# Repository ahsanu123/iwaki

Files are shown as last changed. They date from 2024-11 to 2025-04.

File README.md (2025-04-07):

<p>
  <a href="">
    
  </a>
  <a href="">
    
  </a>
  <a href="">
    
  </a>
  <a href="https://github.com/ahsanu123/iwaki/blob/main/LICENSE">
    
  </a>
</p>

<p align="center">
   <br/>
   Automated Fish Cultivation
</p>

# 🐟 IWAKI - Automated Fish Cultivation

Initial System Design 

```mermaid
---
title: Block Diagram of System
---
classDiagram

note for DCMotor "this will use for spreading food"
note for Board "Use ESP32 to send data into server"
note for Spreader "Mechanic Spreader"

PowerSupply <|-- Board 
Board <|-- DCMotor
Board <|-- TempSensor
Board <|-- ESP32
Board <|-- SalinityAndPH
Board <|-- SSR
Board <|-- IOExpantion

IOExpantion <|-- SolenoidValve

SSR <|-- Pump

Spreader <|-- Board
Hopper <|-- Spreader

Server <|-- Board
Server <|-- Mobile

namespace Electronic {
class IOExpantion
class SalinityAndPH
class Board
class DCMotor
class ESP32
class TempSensor
class SSR
}

namespace Feeder{
class Spreader
class Hopper
}

namespace App{
class Mobile
}

namespace Backend{
class Server
}

```

## 🌳 Logs
- create initial system design, 23 november 2024 at ⏰ 14:26
- decided to use [embassy rust](https://github.com/embassy-rs/embassy) to do firmware, 16 januari 2025 at ⏰ 18:47 

## 🎈 Reference 

- [A Guide to Recirculation Aquaculture](https://openknowledge.fao.org/server/api/core/bitstreams/a0297773-095a-4ae7-9a89-5a3bfb48abc7/content)
- [efishery guide on lele RAS](https://efishery.com/id/resources/budidaya-ikan-lele-sistem-ras/)
- [a freecad manual](https://www.freecad.org/manual/a-freecad-manual.pdf)

<sub>long project with hope will finish. made with ♥️ by ah...</sub>

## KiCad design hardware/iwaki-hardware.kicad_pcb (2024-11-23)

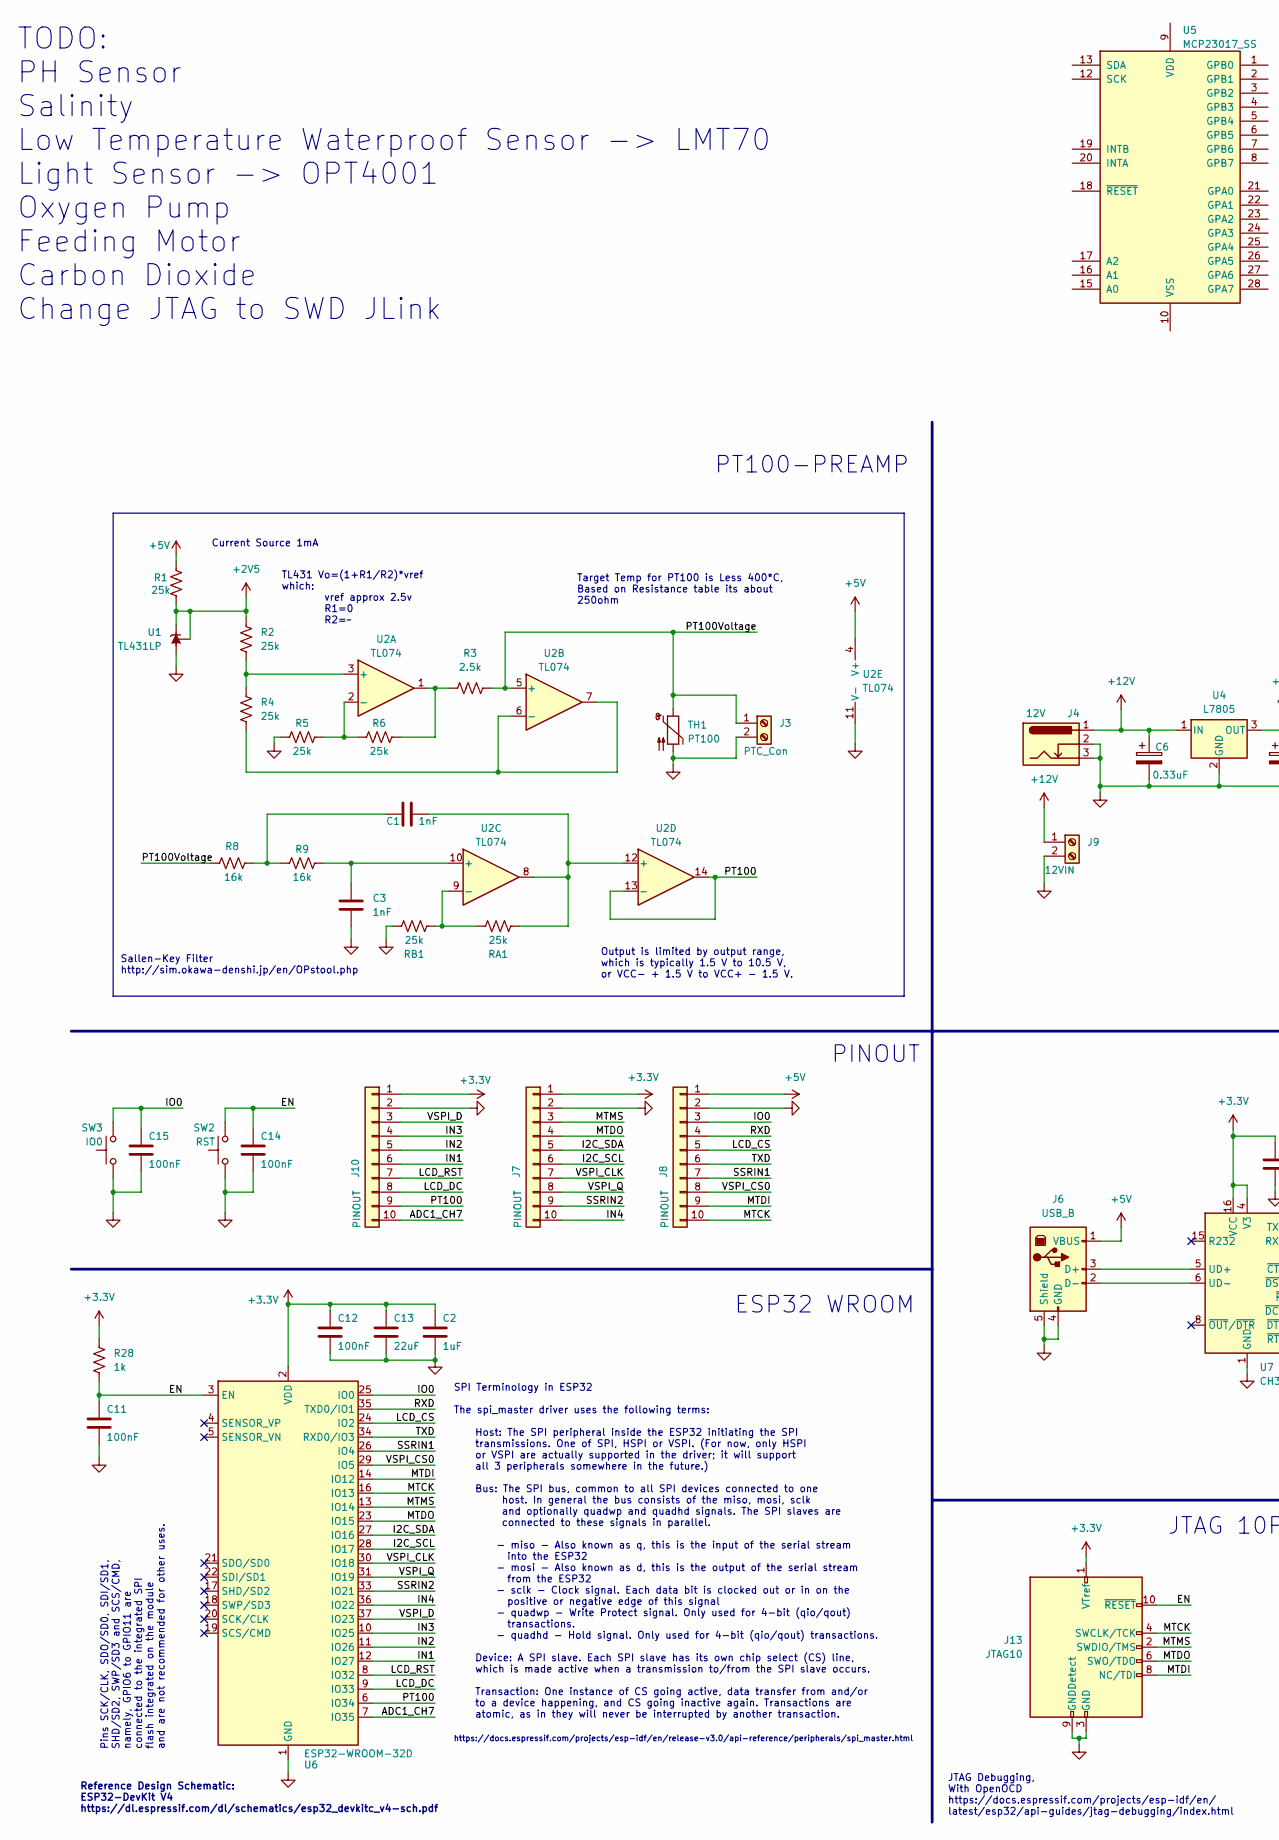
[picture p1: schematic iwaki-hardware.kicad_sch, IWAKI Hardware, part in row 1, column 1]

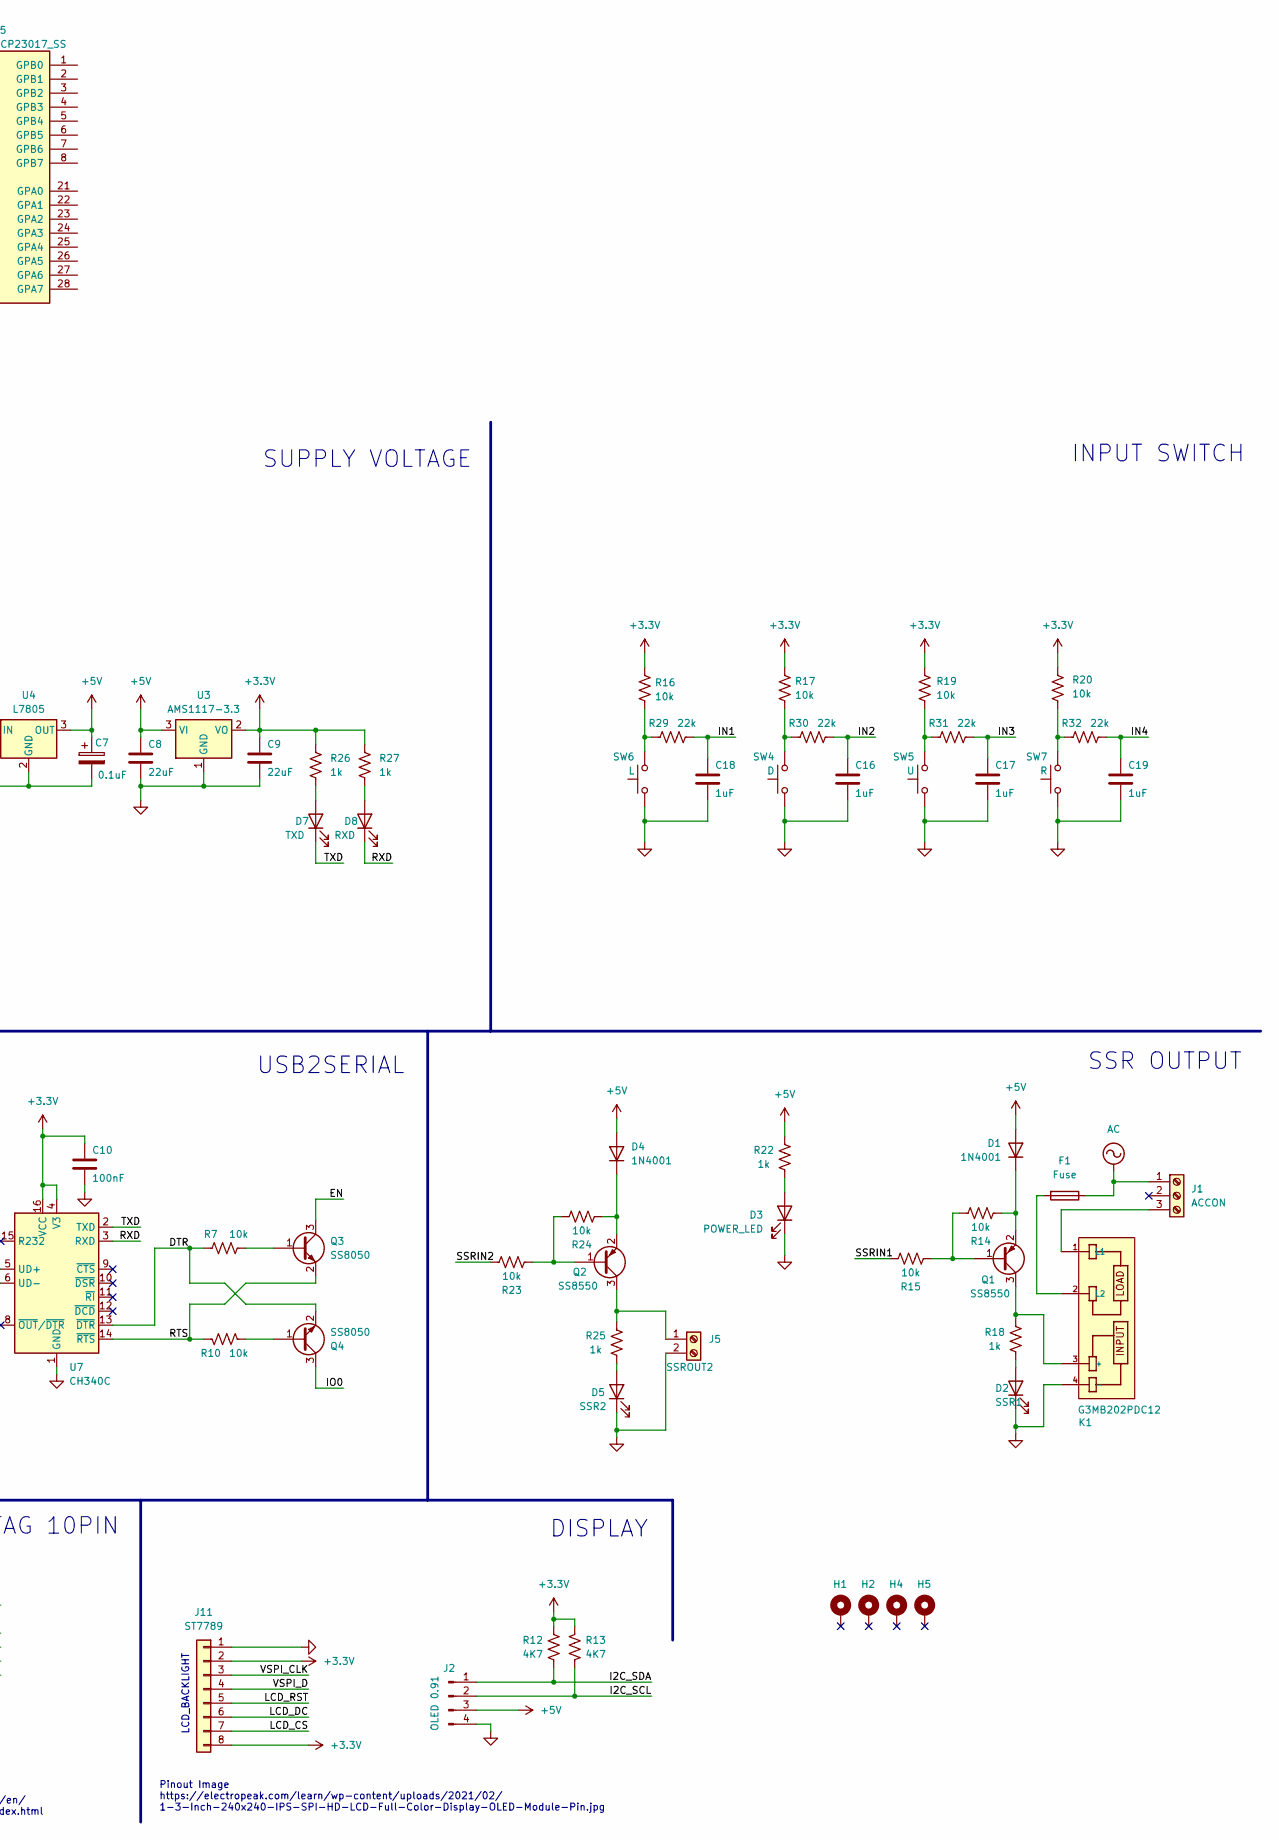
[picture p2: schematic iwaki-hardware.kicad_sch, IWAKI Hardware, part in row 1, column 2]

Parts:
C1, C3: 1nF; C_0805_2012Metric_Pad1.18x1.45mm_HandSolder
C2, C16, C17, C18, C19: 1uF; C_0805_2012Metric_Pad1.18x1.45mm_HandSolder
C6: 0.33uF; C_0805_2012Metric_Pad1.18x1.45mm_HandSolder
C7: 0.1uF; C_0805_2012Metric_Pad1.18x1.45mm_HandSolder
C8, C9, C13: 22uF; C_0805_2012Metric_Pad1.18x1.45mm_HandSolder
C10, C11, C12, C14, C15: 100nF; C_0805_2012Metric_Pad1.18x1.45mm_HandSolder
D1, D4: 1N4001; D_SOD-123
D2: SSR1; LED_1206_3216Metric_Pad1.42x1.75mm_HandSolder
D3: POWER_LED; LED_1206_3216Metric_Pad1.42x1.75mm_HandSolder
D5: SSR2; LED_1206_3216Metric_Pad1.42x1.75mm_HandSolder
D7: TXD; LED_1206_3216Metric_Pad1.42x1.75mm_HandSolder
D8: RXD; LED_1206_3216Metric_Pad1.42x1.75mm_HandSolder
F1: Fuse; Fuseholder_Littelfuse_100_series_5x30mm
H1, H2, H4, H5: MountingHole_Pad; MountingHole_3.2mm_M3_DIN965_Pad
J1: ACCON; TerminalBlock_Phoenix_PT-1,5-3-5.0-H_1x03_P5.00mm_Horizontal
J2: OLED 0.91; PinHeader_1x04_P2.54mm_Vertical
J3: PTC_Con; TerminalBlock_Phoenix_PT-1,5-2-5.0-H_1x02_P5.00mm_Horizontal
J4: 12V; BarrelJack_Horizontal
J5: SSROUT2; TerminalBlock_Phoenix_PT-1,5-2-5.0-H_1x02_P5.00mm_Horizontal
J6: USB_B; USB_B_OST_USB-B1HSxx_Horizontal
J7, J8, J10: PINOUT; PinHeader_1x10_P2.54mm_Vertical
J9: 12VIN; TerminalBlock_Phoenix_PT-1,5-2-5.0-H_1x02_P5.00mm_Horizontal
J11: ST7789; PinSocket_1x08_P2.54mm_Vertical
J13: JTAG10; PinHeader_2x05_P2.54mm_Vertical
K1: G3MB202PDC12; RELAY_G3MB202PDC12; PARTREV N/A
Q1, Q2: SS8550; SOT-23_Handsoldering
Q3, Q4: SS8050; SOT-23_Handsoldering
R1, R2, R4, R5, R6: 25k; R_0805_2012Metric_Pad1.20x1.40mm_HandSolder
R3: 2.5k; R_0805_2012Metric_Pad1.20x1.40mm_HandSolder
R7, R10, R14, R15, R16, R17, R19, R20, R23, R24: 10k; R_0805_2012Metric_Pad1.20x1.40mm_HandSolder
R8, R9: 16k; R_0805_2012Metric_Pad1.20x1.40mm_HandSolder
R12, R13: 4K7; R_0805_2012Metric_Pad1.20x1.40mm_HandSolder
R18, R22, R25, R26, R27, R28: 1k; R_0805_2012Metric_Pad1.20x1.40mm_HandSolder
R29, R30, R31, R32: 22k; R_0805_2012Metric_Pad1.20x1.40mm_HandSolder
RA1: 25k; R_0805_2012Metric_Pad1.20x1.40mm_HandSolder
RB1: 25k; R_0805_2012Metric_Pad1.20x1.40mm_HandSolder
SW2: RST; SW_Push_1P1T_NO_6x6mm_H9.5mm
SW3: IO0; SW_Push_1P1T_NO_6x6mm_H9.5mm
SW4: D; SW_Push_1P1T_NO_6x6mm_H9.5mm
SW5: U; SW_Push_1P1T_NO_6x6mm_H9.5mm
SW6: L; SW_Push_1P1T_NO_6x6mm_H9.5mm
SW7: R; SW_Push_1P1T_NO_6x6mm_H9.5mm
TH1: PT100; TO-92-2_Horizontal2
U1: TL431LP; TO-92_Inline_Wide
U2: TL074; SOIC-14_3.9x8.7mm_P1.27mm
U3: AMS1117-3.3; SOT-223-3_TabPin2
U4: L7805; TO-220F-3_Horizontal_TabDown
U5: MCP23017_SS; SSOP-28_5.3x10.2mm_P0.65mm
U6: ESP32-WROOM-32D
U7: CH340C; SOIC-16_3.9x9.9mm_P1.27mm

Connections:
+2V5: R1.1, R2.1, U1.1 (REF), U1.3 (K)
+3.3V: C2.1, C9.1, C10.1, C12.1, C13.1, J7.1, J10.1, J11.2, J11.8, J13.1 (VTref), R12.2, R13.2, R16.1, R17.1, R19.1, R20.1, R26.1, R27.1, R28.1, U3.2 (VO), U6.2 (VDD), U7.4 (V3), U7.16 (VCC)
+5V: C7.1, C8.1, D1.2 (A), D4.2 (A), J2.3, J6.1 (VBUS), J8.1, R1.2, R22.2, U2.4 (V+), U3.3 (VI), U4.3 (OUT)
+12V: C6.1, J4.1, J9.1, U4.1 (IN)
/ADC1_CH7: J10.10, U6.7 (IO35)
/DTR: Q4.2 (E), R7.2, U7.13 (~DTR)
/EN: C11.1, C14.1, J13.10 (~RESET), Q3.3 (C), R28.2, SW2.2, U6.3 (EN)
/I2C_SCL: J2.2, J7.6, R13.1, U6.28 (IO17)
/I2C_SDA: J2.1, J7.5, R12.1, U6.27 (IO16)
/IN1: C18.1, J10.6, R29.1, U6.12 (IO27)
/IN2: C16.1, J10.5, R30.1, U6.11 (IO26)
/IN3: C17.1, J10.4, R31.1, U6.10 (IO25)
/IN4: C19.1, J7.10, R32.1, U6.36 (IO22)
/IO0: C15.1, J8.3, Q4.3 (C), SW3.2, U6.25 (IO0)
/LCD_CS: J8.5, J11.7, U6.24 (IO2)
/LCD_DC: J10.8, J11.6, U6.9 (IO33)
/LCD_RST: J10.7, J11.5, U6.8 (IO32)
/MTCK: J8.10, J13.4 (SWCLK/TCK), U6.16 (IO13)
/MTDI: J8.9, J13.8 (NC/TDI), U6.14 (IO12)
/MTDO: J7.4, J13.6 (SWO/TDO), U6.23 (IO15)
/MTMS: J7.3, J13.2 (SWDIO/TMS), U6.13 (IO14)
/PT100: J10.9, U2.13 (-), U2.14, U6.6 (IO34)
/PT100Voltage: J3.1, R3.1, R8.2, TH1.1, U2.5 (+)
/RTS: Q3.2 (E), R10.2, U7.14 (~RTS)
/RXD: D8.1 (K), J8.4, U6.35 (TXD0/IO1), U7.3 (RXD)
/SSRIN1: J8.7, R15.1, U6.26 (IO4)
/SSRIN2: J7.9, R23.1, U6.33 (IO21)
/TXD: D7.1 (K), J8.6, U6.34 (RXD0/IO3), U7.2 (TXD)
/VSPI_CLK: J7.7, J11.3, U6.30 (IO18)
/VSPI_CS0: J8.8, U6.29 (IO5)
/VSPI_D: J10.3, J11.4, U6.37 (IO23)
/VSPI_Q: J7.8, U6.31 (IO19)
AC: F1.1, J1.1
GND: C2.2, C3.2, C6.2, C7.2, C8.2, C9.2, C10.2, C11.2, C12.2, C13.2, C14.2, C15.2, C16.2, C17.2, C18.2, C19.2, D2.1 (K), D3.1 (K), D5.1 (K), J2.4, J3.2, J4.2, J4.3, J5.2, J6.4 (GND), J6.5 (Shield), J7.2, J8.2, J9.2, J10.2, J11.1, J13.3 (GND), J13.5 (GND), J13.9 (GNDDetect), K1.4 (-), R5.1, RB1.1, SW2.1, SW3.1, SW4.1, SW5.1, SW6.1, SW7.1, TH1.2, U1.2 (A), U2.11 (V-), U3.1 (GND), U4.2 (GND), U6.1 (GND), U6.15 (GND), U6.38 (GND), U6.39 (GND), U7.1 (GND)
unnamed: C1.2, R8.1, R9.2
unnamed: D1.1 (K), Q1.2 (E), R14.2
unnamed: D2.2 (A), R18.1
unnamed: D3.2 (A), R22.1
unnamed: D4.1 (K), Q2.2 (E), R24.2
unnamed: D5.2 (A), R25.1
unnamed: D7.2 (A), R26.2
unnamed: D8.2 (A), R27.2
unnamed: J1.3, K1.1 (L1)
unnamed: J5.1, Q2.3 (C), R25.2
unnamed: J6.3 (D+), U7.5 (UD+)
unnamed: J6.2 (D-), U7.6 (UD-)
unnamed: K1.3 (+), Q1.3 (C), R18.2
unnamed: F1.2, K1.2 (L2)
unnamed: Q1.1 (B), R14.1, R15.2
unnamed: Q2.1 (B), R23.2, R24.1
unnamed: Q3.1 (B), R7.1
unnamed: Q4.1 (B), R10.1
unnamed: R3.2, R6.1, U2.1
unnamed: R16.2, R29.2, SW6.2
unnamed: R17.2, R30.2, SW4.2
unnamed: R19.2, R31.2, SW5.2
unnamed: R20.2, R32.2, SW7.2
unnamed: R2.2, R4.1, U2.3 (+)
unnamed: R5.2, R6.2, U2.2 (-)
unnamed: R4.2, U2.6 (-), U2.7
unnamed: C3.1, R9.1, U2.10 (+)
unnamed: RA1.1, RB1.2, U2.9 (-)
unnamed: C1.1, RA1.2, U2.8, U2.12 (+)

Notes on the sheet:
Sallen-Key Filter http://sim.okawa-denshi.jp/en/OPstool.php
Reference Design Schematic: ESP32-DevKit V4 https://dl.espressif.com/dl/schematics/esp32_devkitc_v4-sch.pdf
SUPPLY VOLTAGE
TODO: PH Sensor Salinity Low Temperature Waterproof Sensor -> LMT70 Light Sensor -> OPT4001 Oxygen Pump Feeding Motor Carbon Dioxide Change JTAG to SWD JLink
JTAG 10PIN
Output is limited by output range, which is typically 1.5 V to 10.5 V, or VCC- + 1.5 V to VCC+ - 1.5 V.
Pinout Image https://electropeak.com/learn/wp-content/uploads/2021/02/ 1-3-Inch-240x240-IPS-SPI-HD-LCD-Full-Color-Display-OLED-Module-Pin.jpg
ESP32 WROOM
PT100-PREAMP
DISPLAY
Pins SCK/CLK, SDO/SD0, SDI/SD1, SHD/SD2, SWP/SD3 and SCS/CMD, namely, GPIO6 to GPIO11 are connected to the integrated SPI flash integrated on the module and are not recommended for other uses.
TL431 Vo=(1+R1/R2)*vref which: vref approx 2.5v R1=0 R2=~
Target Temp for PT100 is Less 400*C, Based on Resistance table its about 250ohm
PINOUT
Current Source 1mA
JTAG Debugging, With OpenOCD https://docs.espressif.com/projects/esp-idf/en/ latest/esp32/api-guides/jtag-debugging/index.html
SPI Terminology in ESP32 The spi_master driver uses the following terms: Host: The SPI peripheral inside the ESP32 initiating the SPI transmissions. One of SPI, HSPI or VSPI. (For now, only HSPI or VSPI are actually supported in the driver; it will support all 3 peripherals somewhere in the future.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
LCD_BACKLIGHT
USB2SERIAL
INPUT SWITCH
SSR OUTPUT

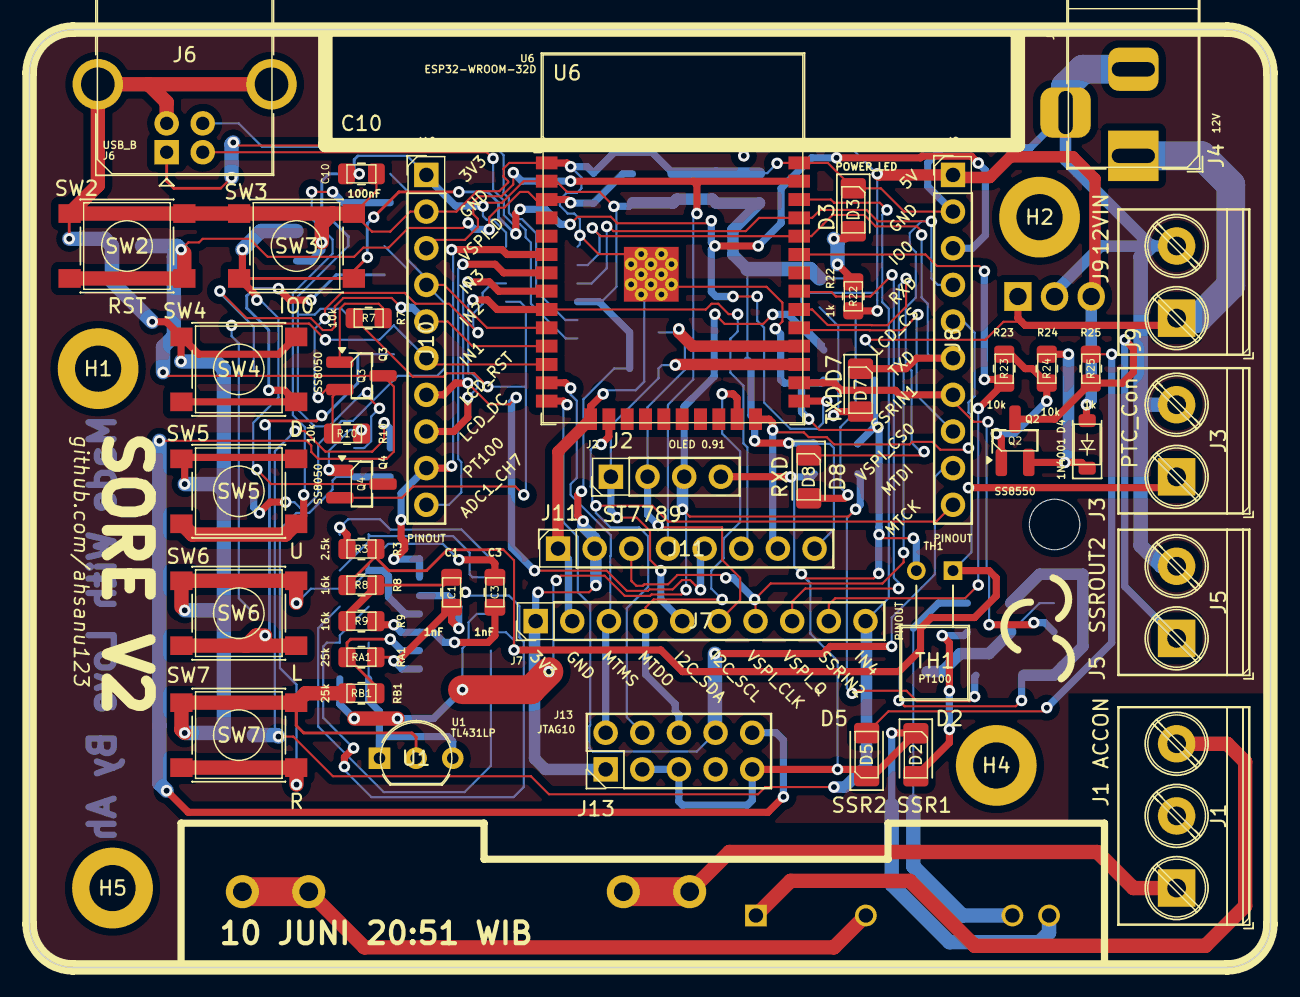
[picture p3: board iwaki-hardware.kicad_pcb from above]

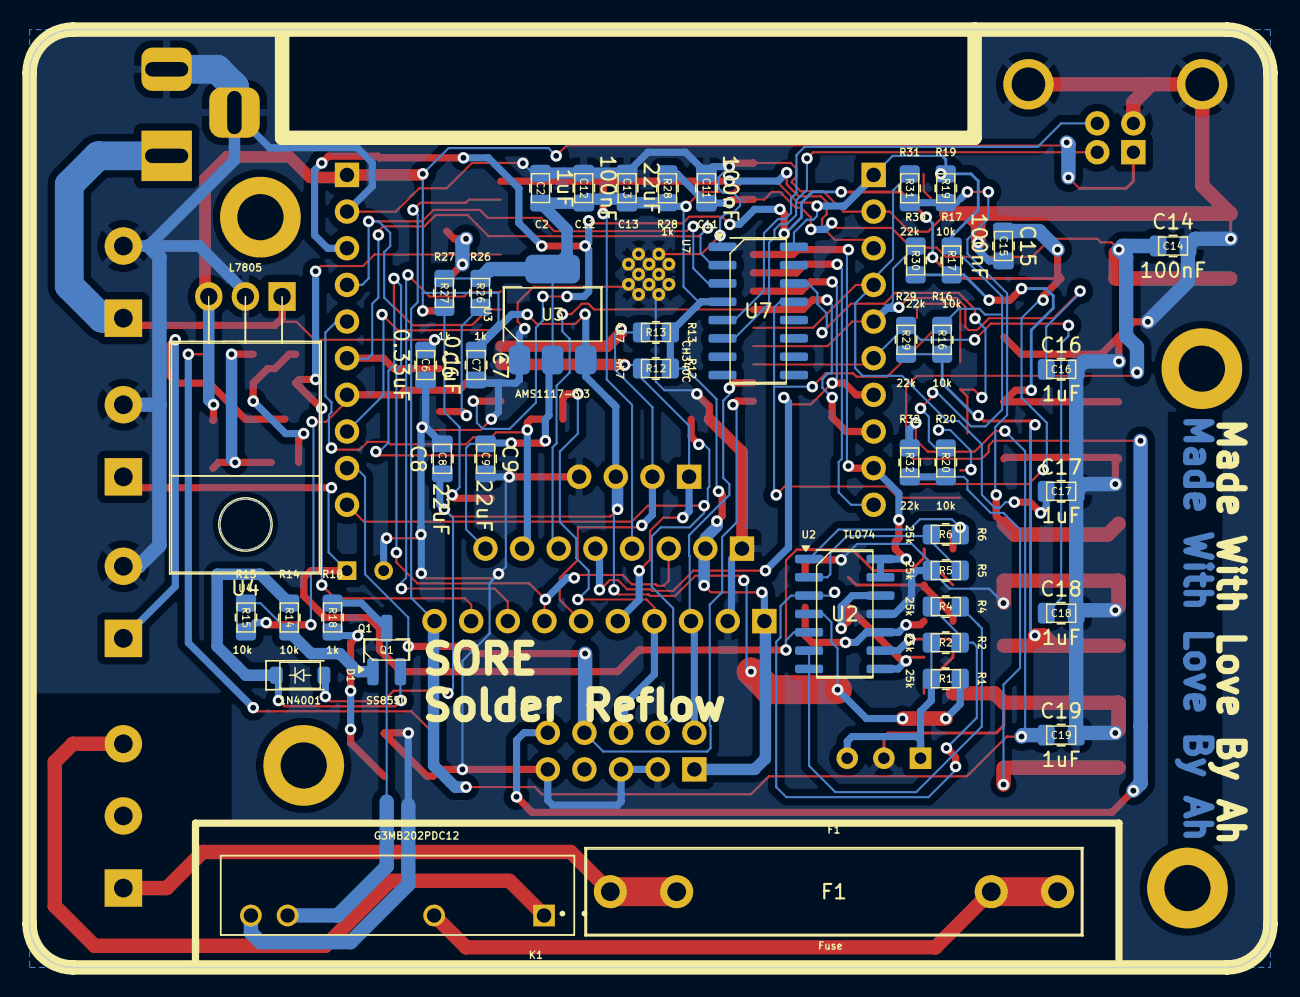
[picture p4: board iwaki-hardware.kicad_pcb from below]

Board: 2 copper layers, 86.0 x 65.0 mm, 91 parts (43 on the bottom side), 63 nets.
